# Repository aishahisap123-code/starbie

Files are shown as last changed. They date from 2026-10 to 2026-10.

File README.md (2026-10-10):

# Starcade
Starcade is a motion-controlled handheld arcade pet and retro game console. Inspired by classic handhelds and desktop pets, it brings interactive games, motion sensing, and sound effects together in a custom wing-shaped PCB. Instead of relying solely on traditional buttons, you interact with games, menus, and pet reactions by physically tilting, shaking, and rotating the board.



# What It Is
Starcade is designed to sit on your desk, display custom animations on a bright OLED screen, and react directly to how you handle it. Tilting, rotating the encoder, pressing action buttons, and listening to sound effects and LED animations are all core to the physical experience.

The board includes an ESP32-C3 microcontroller, 0.96" OLED display, 6-axis MPU6050 motion sensor, DHT11 temperature/humidity sensor, addressable WS2812B RGB LEDs, active buzzer, and a rotary encoder inside a compact wing-shaped PCB design. It is USB-C powered and optimized for easy component assembly and custom firmware hacking.

# Why?
This project was created as a complete, hands-on hardware and embedded software tutorial, taking builders all the way from custom PCB layout and Gerber manufacturing to writing full Arduino firmware from scratch.

# Project Status
The custom PCB layout, ground plane generation, Gerber manufacturing exports, and component DRC checks are complete and verified. Starter Arduino IDE code and pin assignment maps are set up to handle display drivers, motion detection, RGB lighting, and menu navigation.

# Software
Firmware/ contains modular, self-contained Arduino IDE sketches for the Seeed Studio XIAO ESP32-C3. Builders customize pin assignments, motion sensitivity, sound effects, LED lighting modes, and sensor readouts at the top of the sketch. See the Firmware/ README for library setup, board manager links, and flashing instructions.

# Repository Contents
PCB/ — KiCad source files, schematic diagrams, and ready-to-upload Gerber fabrication exports (.zip)

Renders/ — 2D/3D front and back PCB renders with custom silkscreen artwork (STARCADE35, AXISAP, and emblems)

Project Guide.md — Step-by-step assembly, soldering, and manufacturing guide

Firmware/ — Arduino IDE starter sketches for OLED graphics, MPU6050 motion tracking, DHT11 environmental readings, WS2812B LEDs, buzzer audio, and rotary menu navigation

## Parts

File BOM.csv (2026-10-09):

# Starcade 35 – bill of materials
<!-- Generated by Half Life from project cmuwsvaz90ai901osuojz3ds5. Edits here are overwritten on the next sync. -->
<!-- Generated: 2026-10-09T14:10:22.091Z -->
> [!NOTE]
> This parts list is mirrored from [Half Life](https://halflife.hackclub.com). Editing it here will not change the platform's copy, and the next sync overwrites this file.
 | Week | Tier | Parts funding
 | --- | --- | ---
 | Week 1 | Tier 1 | $30.00
 | Part | What it's for | Qty | Unit | Total | Vendor
 | --- | --- | --- | --- | --- | ---
 | [ESP32 c3 mini](https://www.aliexpress.com/item/1005008791937363.html?mp=1 | The main brain that runs your software, handles Wi-Fi/Bluetooth, and controls all components. | 1 | $8.34 | $8.34 | [Aliexpress](https://www.aliexpress.com/item/1005008791937363.html?mp=1
 | [MPU-6050 MPU6050 Module](https://www.aliexpress.com/item/1005009668682906.html?mp=1 | accelerometer and gyro used for tilt-based motion controls in games. | 1 | $1.73 | $1.73 | [Aliexpress](https://www.aliexpress.com/item/1005009668682906.html?mp=1
 | [DHT11](https://www.aliexpress.com/item/1005008953430940.html?mp=1 | temp sensor | 1 | $1.40 | $1.40 | [Aliexpress](https://www.aliexpress.com/item/1005008953430940.html?mp=1
 | [pcb board](https://cart.jlcpcb.com/shopcart/cart) | pcb | 1 | $8.67 | $8.67 | [JLCPCB](https://cart.jlcpcb.com/shopcart/cart)
 | [0.96 inch OLED](https://www.aliexpress.com/item/1005006141235306.html?mp=1 | the display | 1 | $0.93 | $0.93 | [Aliexpress](https://www.aliexpress.com/item/1005006141235306.html?mp=1
 | [rotary encoder](https://www.aliexpress.com/item/1005008583446552.html?curPageLogUid=ELZrBR1cT0gn | navigation | 1 | $5.20 | $5.20 | [Aliexpress](https://www.aliexpress.com/item/1005008583446552.html?curPageLogUid=ELZrBR1cT0gn
 | [buzzer](https://www.aliexpress.com/item/1005008789575850.html?mp=1 | make sound | 1 | $1.82 | $1.82 | [Aliexpress](https://www.aliexpress.com/item/1005008789575850.html?mp=1
 | [buttons](https://www.aliexpress.com/item/1005001629177989.html?curPageLogUid=qgexuiVhkgyf | navigation and menu and gameplay | 1 | $1.61 | $1.61 | [Aliexpress](https://www.aliexpress.com/item/1005001629177989.html?curPageLogUid=qgexuiVhkgyf
 | **Parts subtotal** | — | — | — | **$29.70** | —
 | **Tax & shipping** | — | — | — | **$0.00** | —
 | **Total** | — | — | — | **$29.70** | —
$0.30 left of the tier's funding.

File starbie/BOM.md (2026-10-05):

# Starbie — bill of materials

<!-- Generated by Half Life from project cmuvag7340foz01smya712y6w. Edits here are overwritten on the next sync. -->
<!-- Generated: 1970-01-01T00:00:00.000Z -->

> [!NOTE]
> This parts list is mirrored from [Half Life](https://halflife.hackclub.com). Editing it here will not change the platform's copy, and the next sync overwrites this file.

| Week | Tier | Parts funding |
| --- | --- | --- |
| Week 1 | Tier 1 | $30.00 |

_No parts listed yet._

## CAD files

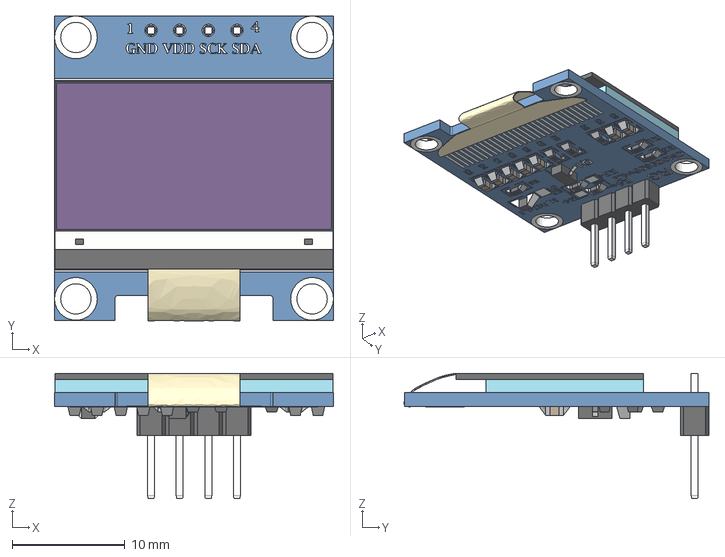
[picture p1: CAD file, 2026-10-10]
starbie/3D Models/0.96'' OLED Display.step
24.8 x 27.1 x 11.1 mm

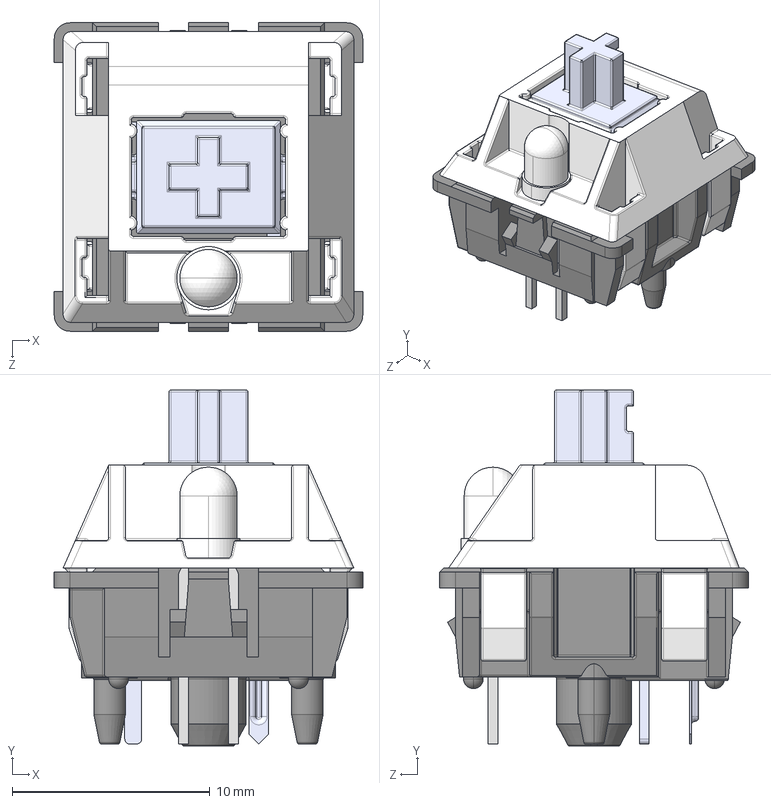
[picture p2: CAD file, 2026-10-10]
starbie/3D Models/Cherry MX.STEP
15.6 x 18.0 x 15.6 mm
Bottom
Pulsador
Top
Pieza5^Cherry MX
Pin1
Pin2
Led 3mm_trans

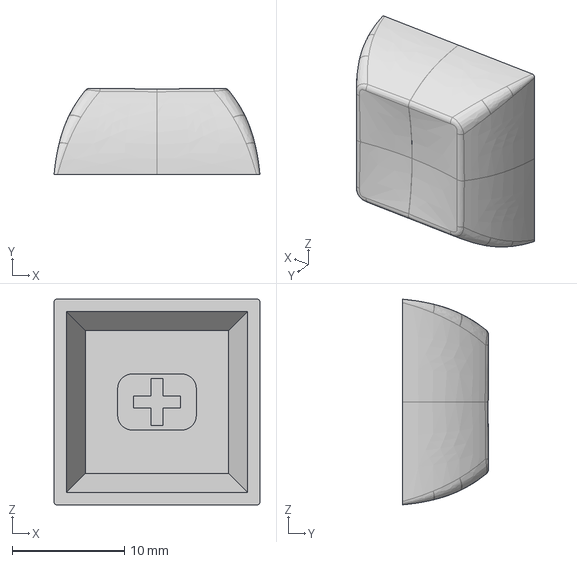
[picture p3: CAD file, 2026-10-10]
starbie/3D Models/DSA_Keycap_CherryMX.step
18.3 x 7.69 x 18.3 mm

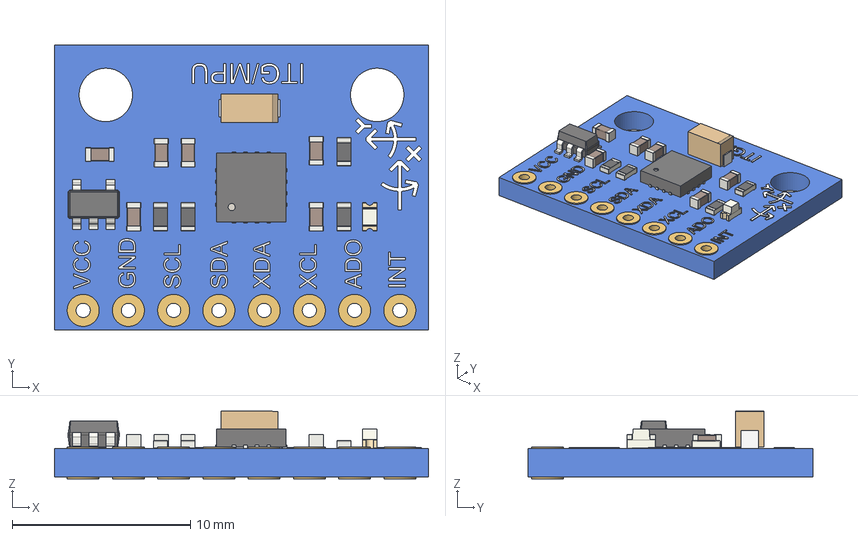
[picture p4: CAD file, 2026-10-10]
starbie/3D Models/GY-521_MPU6050 Accelerometer.step
21.0 x 16.0 x 3.80 mm
PCB
trou1
trou002
trou003
trou004
trou005
trou006
trou007
trou008
Text_X
Symb_Y
Symb_X
Text_Y
Text_VCC
Text_GND
Text_SCL
Text_SDA
Text_XDA
Text_XCL
Text_ADO
Text_INT
R_0603_1608Metric
R_0603_1608Metric001
R_0603_1608Metric002
R_0603_1608Metric003
C_0603_1608Metric
C_0603_1608Metric001
C_0603_1608Metric002
C_0603_1608Metric003
Corps002
Corps001 (Mirror #1)
C_0603_1608Metric004
C_0603_1608Metric005
LED_0603_1608Metric_Castellated
QFN_16_1EP_4x4mm_P065mm_EP21x21mm
Text_ITGMPU
SOT_23_5
Corps001

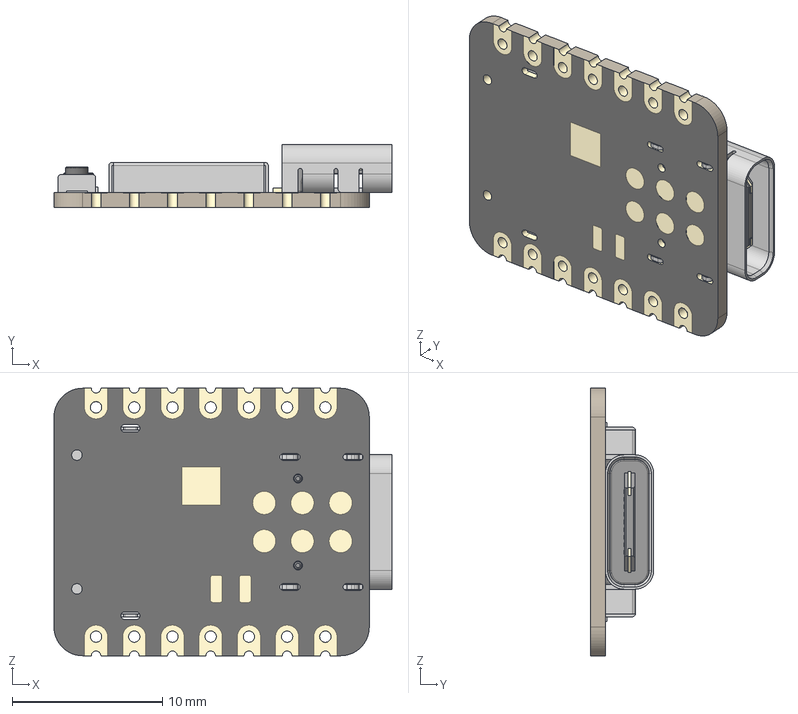
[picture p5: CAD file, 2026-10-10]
starbie/3D Models/Seeed Studio XIAO-ESP32-C3.step
22.5 x 4.21 x 17.8 mm
BOSS-EXTRUDE14_8_
BOSS-EXTRUDE7_4_
BOSS-EXTRUDE7_3_
BOSS-EXTRUDE14_4_
BOSS-EXTRUDE14_2_
BOSS-EXTRUDE14_11_
BOSS-EXTRUDE7_7_
BOSS-EXTRUDE14_9_
BOSS-EXTRUDE14_3_
BOSS-EXTRUDE14_7_
MIRROR2
BOSS-EXTRUDE14_5_
BOSS-EXTRUDE14_12_
BOSS-EXTRUDE7_8_
BOSS-EXTRUDE7_1_
BOSS-EXTRUDE14_10_
BOSS-EXTRUDE7_9_
BOSS-EXTRUDE14_6_
BOSS-EXTRUDE14_1_
BOSS-EXTRUDE7_6_
BOSS-EXTRUDE7_2_
CUT-EXTRUDE5
BOSS-EXTRUDE7_5_
U.FL Connector v1
Button (1) x 2
Shield

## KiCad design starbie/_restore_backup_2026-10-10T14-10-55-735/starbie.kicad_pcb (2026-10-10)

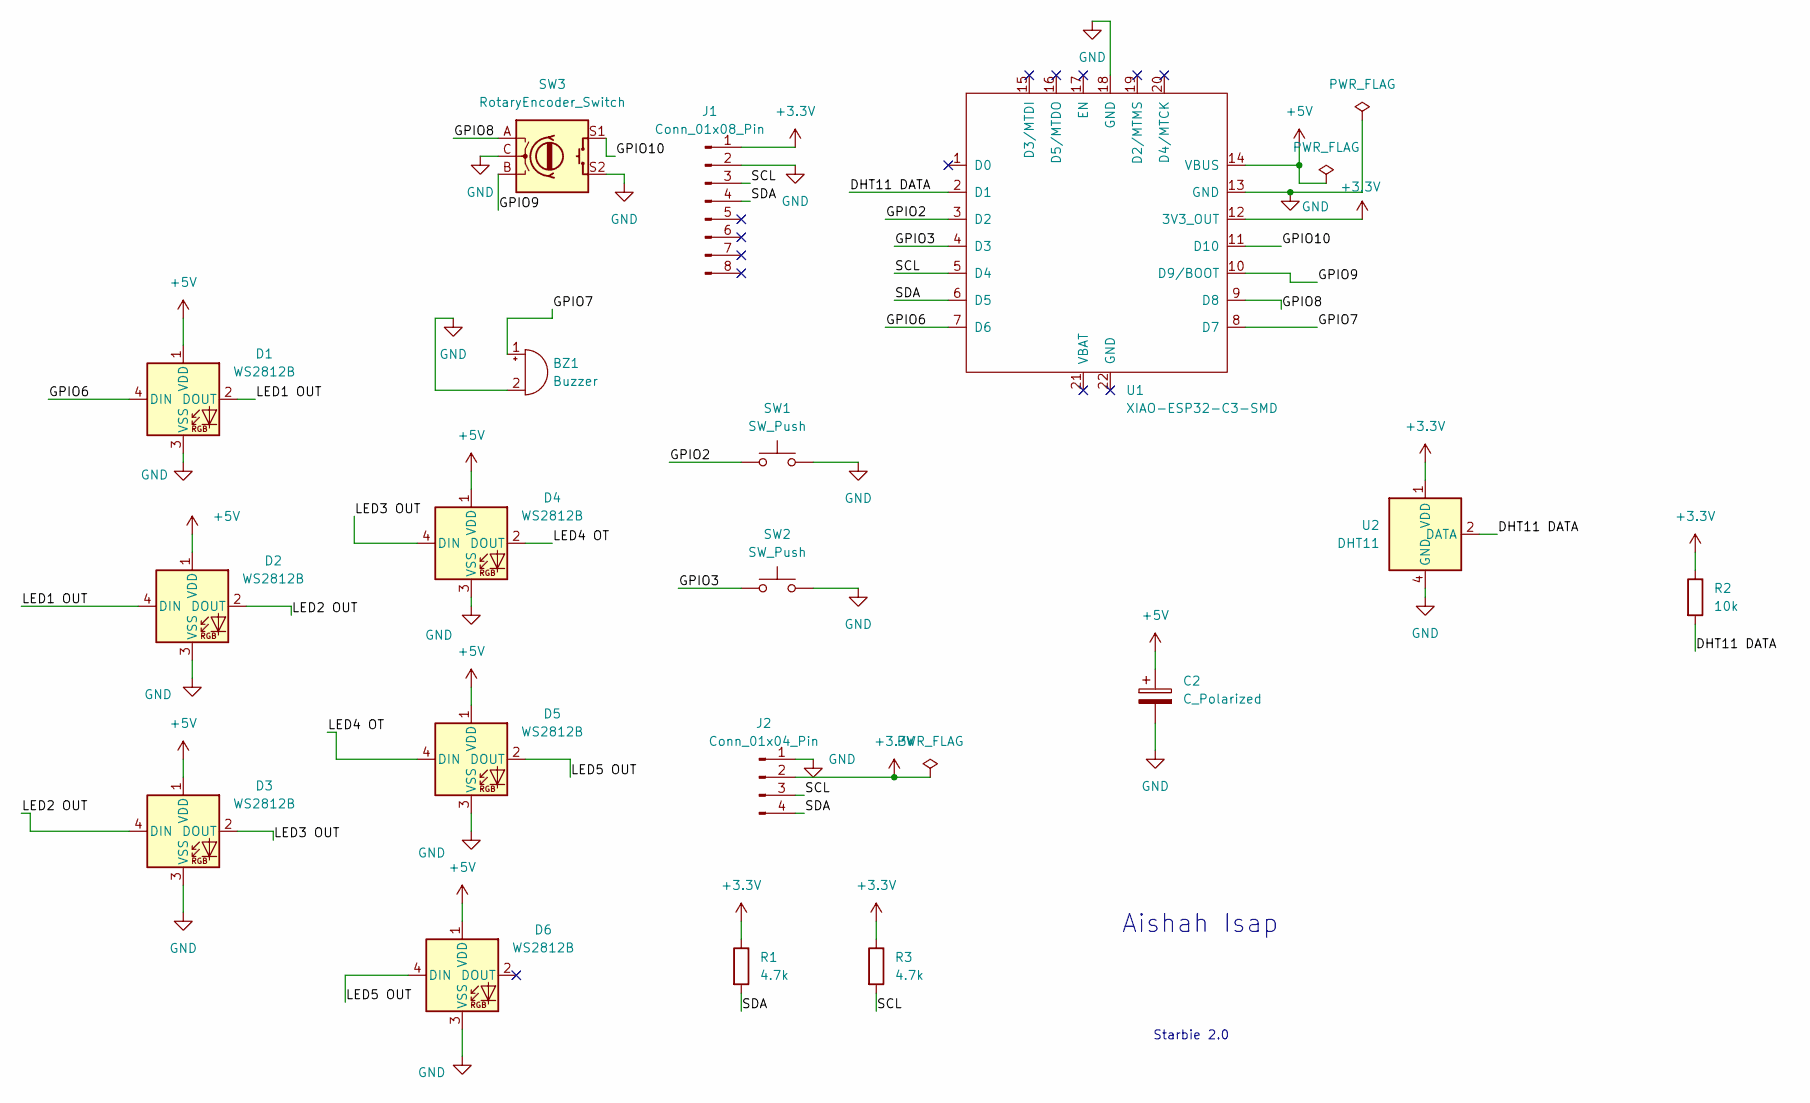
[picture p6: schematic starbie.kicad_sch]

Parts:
BZ1: Buzzer; Buzzer_12x9.5RM7.6
C2: C_Polarized; CP_Radial_D8.0mm_P3.50mm
D1, D2, D3, D4, D5, D6: WS2812B; LED_WS2812B_PLCC4_5.0x5.0mm_P3.2mm
J1: Conn_01x08_Pin; MPU6050_Module
J2: Conn_01x04_Pin; Display_128x64_096_I2C
R1, R3: 4.7k; R_Axial_DIN0204_L3.6mm_D1.6mm_P7.62mm_Horizontal
R2: 10k; R_Axial_DIN0204_L3.6mm_D1.6mm_P7.62mm_Horizontal
SW1, SW2: SW_Push; SW_PUSH_6mm
SW3: RotaryEncoder_Switch; RotaryEncoder_Alps_EC11E-Switch_Vertical_H20mm
U1: XIAO-ESP32-C3-SMD; MCU_Seeed_ESP32C3
U2: DHT11; Aosong_DHT11_5.5x12.0_P2.54mm

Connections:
+3.3V: J1.1, J2.2, R1.1, R2.1, R3.1, U1.12 (3V3_OUT), U2.1 (VDD)
+5V: C2.1, D1.1 (VDD), D2.1 (VDD), D3.1 (VDD), D4.1 (VDD), D5.1 (VDD), D6.1 (VDD), U1.14 (VBUS)
/DHT11 DATA: R2.2, U1.2 (D1), U2.2 (DATA)
/GPIO2: SW1.1, U1.3 (D2)
/GPIO3: SW2.1, U1.4 (D3)
/GPIO6: D1.4 (DIN), U1.7 (D6)
/GPIO7: BZ1.1 (+), U1.8 (D7)
/GPIO8: SW3.A, U1.9 (D8)
/GPIO9: SW3.B, U1.10 (D9/BOOT)
/GPIO10: SW3.S1, U1.11 (D10)
/LED1 OUT: D1.2 (DOUT), D2.4 (DIN)
/LED2 OUT: D2.2 (DOUT), D3.4 (DIN)
/LED3 OUT: D3.2 (DOUT), D4.4 (DIN)
/LED4 OT: D4.2 (DOUT), D5.4 (DIN)
/LED5 OUT: D5.2 (DOUT), D6.4 (DIN)
/SCL: J1.3, J2.3, R3.2, U1.5 (D4)
/SDA: J1.4, J2.4, R1.2, U1.6 (D5)
GND: BZ1.2 (-), C2.2, D1.3 (VSS), D2.3 (VSS), D3.3 (VSS), D4.3 (VSS), D5.3 (VSS), D6.3 (VSS), J1.2, J2.1, SW1.2, SW2.2, SW3.C, SW3.S2, U1.13 (GND), U1.18 (GND), U2.4 (GND)

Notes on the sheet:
Starbie 2.0
Aishah Isap

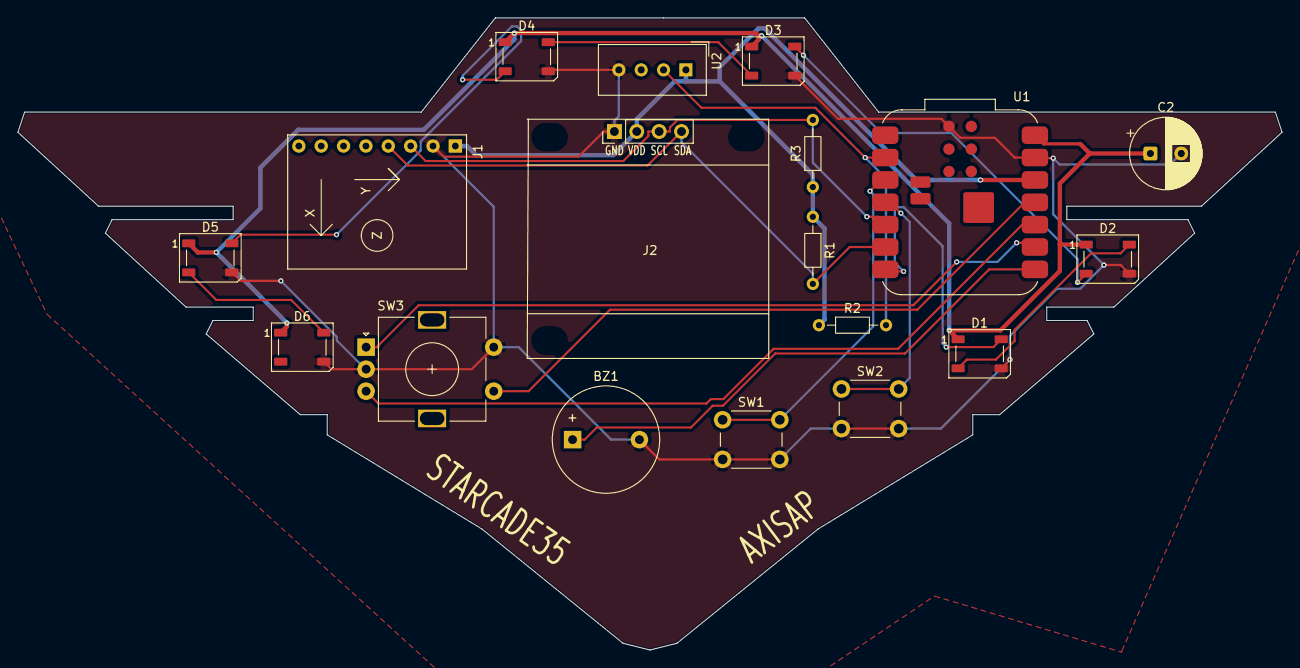
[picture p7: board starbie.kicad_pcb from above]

Board: 2 copper layers, 143.6 x 71.8 mm, 18 parts (0 on the bottom side), 18 nets.

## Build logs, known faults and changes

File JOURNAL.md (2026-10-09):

# Starcade 35 – devlog

<!-- Generated by Half Life from project cmuwsvaz90ai901osuojz3ds5. Edits here are overwritten on the next sync. -->
<!-- Generated: 2026-10-07T19:00:14.272Z -->

> [!NOTE]
> This devlog is mirrored from [Half Life](https://halflife.hackclub.com). Editing it here will not change the platform's copy, and the next sync overwrites this file.

> A tiny motion-controlled digital pet, basically a desktop Tamagotchi. Totally not a Starboy. I have revised the starter project and added extra features such as 6x RGB LEDs, a buzzer, a rotary encoder, dual push buttons, and a motion sensor, turning it into a live environmental desk companion that instantly doubles as a retro handheld for games like Snake.

| Week | Tier | Hours logged | Entries |
| --- | --- | --- | --- |
| Week 1 | Tier 1 | 10h | 2 |

## Contents

1. [2026-10-06 – Session 1: Setting Up KiCad, Schematic Design & My First Battle with Footprint Errors](#2026-10-06-session-1-setting-up-kicad-schematic-design-my-fi)
2. [2026-10-07 – Starcade Hardware Session 2: Final PCB Layout, Routing, and Error Cleared](#2026-10-07-starcade-hardware-session-2-final-pcb-layout-rout)

## Design

### 2026-10-06 – Session 1: Setting Up KiCad, Schematic Design & My First Battle with Footprint Errors

**4.5h**

Session 1: Setting Up KiCad, Schematic Design & My First Battle with Footprint Errors

Today was all about kicking off Starbie 2.0, the upgraded version of the HackClub original project, now powered by the Seeed Studio XIAO ESP32-C3. The plan was to get everything built in KiCad's schematic editor, clear out electrical errors, map all the physical footprints, and finally push everything into the PCB editor so I can start laying out the board.

It turned into a solid 4.5-hour grind (13:30 to 18:00), but I went from having zero files to a fully connected, error-free PCB layout ready for routing! Here is a breakdown of everything that happened, what went wrong, and how I fixed it.

Downloading KiCad & Importing Custom Libraries
Before drawing a single wire, I had to get the software environment ready. Because Starbie 2.0 uses specific hardware modules, like an I2C 0.96" OLED display and an MPU6050 accelerometer, the standard KiCad built-in library didn't have everything I needed out of the box.

	I downloaded KiCad and grabbed custom component libraries (.pretty folders for footprints and .sym files for schematic symbols).

	I went into KiCad's Library Manager to manually link these imported symbol and footprint paths so they’d actually show up when searching for components.

Drawing the Schematic & Fighting ERC Errors
Once the canvas was ready, I dropped in the main brain (XIAO ESP32-C3) alongside the rest of Starbie 2.0's hardware lineup:
	Sensors & Input: DHT11 temperature/humidity sensor, MPU6050 6-DOF gyro, 2x tactile push buttons, and a 5-pin rotary encoder.
	Outputs & Audio: 6x WS2812B addressable RGB LEDs, a buzzer, and the header connector for the OLED screen.

	Passives: Decoupling capacitors and pull-up/limiting resistors.
Wiring everything up was smooth until I ran the Electrical Rules Check (ERC), which immediately threw red flags all over my power rails (+3.3V, +5V, and GND).

The ERC Confusion:
KiCad is super picky, it expects every power rail to have a dedicated power output pin driving it. Because the XIAO board feeds power through regular module pins rather than a traditional regulator symbol, KiCad assumed my power lines were floating in mid-air without any power source.

The Fix (PWR_FLAG):
I learned about a special KiCad symbol called the PWR_FLAG (Power Flag). It isn't a physical part that gets soldered to the board, it's just a dummy signal for KiCad’s internal checker. Dropping three PWR_FLAG symbols onto the canvas and wiring them to +3.3V, +5V, and GND cleared the ERC errors instantly.

Footprint Assignment Chaos
With the schematic validated, I opened the Footprint Assignment Tool to link every schematic symbol to an actual physical hardware footprint. This step turned out to be a massive game of trial-and-error:
	Hunting Down the Rotary Encoder:
I spent way too long trying to find the right footprint for the 5-pin rotary encoder. Typing generic terms like "encoder" into the search bar wasn't pulling up what I needed. I had to manually clear the search filters, navigate into the Rotary_Encoder library category, and find RotaryEncoder_Alps_EC11E-Switch_Vertical_H20mm—which matches the exact 12mm vertical knob package I'm using.

	Accidental Microchip Packages:
KiCad assigned some bizarre default footprints to my passive parts. My 12mm buzzer and 470 µF electrolytic capacitor somehow got mapped to SOIC-8 (a tiny 8-pin surface-mount microchip package!). My push buttons were also accidentally mapped to full Cherry MX mechanical keyboard switch footprints.

	Cleaning Up the Mappings:
I manually went line-by-line to correct everything:
	Resistors (R1, R2): Set to axial through-hole (R_Axial_DIN0204).
	LEDs (D1–D6): Set to standard 5050 surface-mount addressable LEDs (LED_WS2812B_PLCC4_5.0x5.0mm).
	Capacitor (C2) & Buzzer (BZ1): Fixed from SOIC-8 to a radial through-hole footprint (CP_Radial_D8.0mm) and a standard 12mm buzzer footprint (Buzzer_12x9.5mm).
Converting to PCB & The 8 Red Pad Errors

With all footprints assigned, I hit Tools → Update PCB from Schematic (or F8), expecting my board layout to pop open cleanly. Instead, KiCad blocked the export with 8 red errors:
Why this happened:
The original Starbie project used a simple 14-pin DIP footprint for the main board. But because Starbie 2.0 takes advantage of additional pin connections on the Seeed XIAO ESP32-C3 symbol (pins 15 through 22 for extra sensing/audio), the schematic symbol had 22 active pins. When KiCad tried to map a 22-pin symbol onto a 14-pin footprint, it freaked out because pads 15–22 physically didn't exist on that DIP layout!

The Fix:
I jumped back into the Footprint Assignment Tool and changed U1's footprint from the old imported DIP model to rf_module:mcu_seed_esp32c3. This footprint includes all 22 surface-mount castellated and bottom pads matching the XIAO board layout.

Smooth Sailing into the PCB Editor
I ran F8 again, and this time the error count dropped to 0!
There were two minor warnings regarding SW3 pad MP (mechanical mounting pads on the rotary encoder casing that don't have electrical connections in the schematic), but those are strictly mechanical and safe to ignore.
I clicked Update PCB, closed the dialog, and boom, all my component footprints popped onto the black PCB canvas connected by green lines. Starbie 2.0 is officially ready for placement and trace routing!

Key Lessons Learned Today
	PWR_FLAG is a lifesaver: If your board gets power through a header or module rather than an on-board regulator symbol, ERC will complain until you manually add power flags.
	Check pin counts on module footprints: Always make sure your footprint has the exact same number of physical pads as your schematic symbol pins, especially when upgrading a design to use more feature pins on a microcontroller.

	Don't trust default footprint mappings: Double-check passive footprints before exporting so you don't accidentally try soldering a capacitor onto an IC chip footprint!

Total Time Spent: 4.5 hours (13:30 – 18:00)





















### 2026-10-07 – Starcade Hardware Session 2: Final PCB Layout, Routing, and Error Cleared

**5.5h**

Starcade Hardware Session 2: Final PCB Layout, Routing, and Error Cleared

Today Objective
My main goal today was to finish up the entire pcb design, place down every single component, shape the board itself, and fix all remaining visual and design errors so the hardware side is completely done.

What I Did Today
I spent time laying out all the physical components on the board and shaping the actual pcb outline. I designed the board shape specifically so it works well for both motion sensing and gaming controls, keeping the layout comfortable and functional. When placing the seeed studio xiao esp32 module, I made sure it was positioned hanging slightly off the edge of the board, which keeps the antenna area clear for a better signal and allows easy access to the usb port.

After finalizing the board edge boundaries, I started routing all the electrical connections across the entire PCB. I used different trace widths depending on what the line was doing, using thick traces for power lines to handle the current smoothly and thinner traces for all the signal lines connecting the microcontroller to the sensors, screen, leds, and buttons.

I also worked on the 3d models for the xiao esp32 and the oled screen, adjusting their height offsets and rotations to fix visual glitching where parts were clipping through the board surface. I verified the rest of the components, including the addressable rgb leds, the buzzer, the motion sensor chip, the rotary encoder footprint holes, and the custom dallas wings logo on the silkscreen layer. To cap off the session, I ran design checks on the whole board and cleared up every single error so the entire layout is clean.

Mistakes I Ran Into and How I Fixed Them
Downloaded Files Turning Into Web Code
One annoying problem I ran into was downloading 3d files for the rotary encoder dial. When saving files from CAD sites, the browser was saving raw website code instead of proper 3d model data, even though the file name ended with a model extension like step or wrl.

Because the files were secretly web code, the software could not read them and left the encoder invisible in the 3d preview. After realizing the downloaded file was corrupted text, I remembered that 3d models are purely cosmetic anyway. The footprint drill holes and copper pads on the PCB are what actually matter for manufacturing, so I removed the bad file link to keep the project files clean.

Misaligned Pins and Model Offsets
Another issue was that generic 3d models did not align with the footprint holes right away. When loading in models, the pins would often be rotated sideways by ninety degrees or floating off to the side of the actual pads.

This happened because the center point of the 3d model file did not match the center point of my pcb footprint. To fix it, I went into the properties, turned the model along the z axis, and shifted the offset values until the pins lined up over the through holes, which confirmed that physical footprint pad locations always take priority over visual models.

Routing Violations and Board Boundary Clearance
While routing the thick power lines and thin signal wires across the board, I ran into a few design check errors where traces were running too close to the board edge boundaries or crossing each other improperly.

I had to go back through the tight spots, nudge the traces further inside the board edge constraints, and adjust the spacing between signal lines. Fixing those clearances brought the error count down to zero and made sure the board will be manufactured without short circuits or fabrication flaws.

Wrap Up
With all the components placed, the custom shape defined, the routing completed with correct wire thicknesses, and every single error cleared out, the physical pcb design is officially finished. The board is fully laid out and ready for the next phase.

Total time spent: 5.5 hours (12:30 - 14:30, 15:30 - 18:00)





















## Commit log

2026-10-06 Update JOURNAL.md with KiCad setup details
    Documented the process of setting up KiCad for the Starbie 2.0 project, including troubleshooting ERC errors, footprint assignments, and lessons learned during the PCB layout preparation.
2026-10-06 Update JOURNAL.md with KiCad setup details
    Documented the process of setting up KiCad for the Starbie 2.0 project, including schematic design, footprint assignments, and resolving ERC errors.
2026-10-06 Insert new image in JOURNAL.md
    Added a new image to the journal.
2026-10-18 Add BOM link to README
2026-10-19 Add bill of materials for Starcade 35 project
    Added detailed bill of materials for the Starcade 35 project, including parts, costs, and vendor information.
2026-10-19 Revise BOM with updated parts and funding details
    Updated the bill of materials with detailed parts list and links.
2026-10-26 Add starbie-B Silkscreen file
2026-10-30 Expand README with project features and functionalities
    Added detailed features of the Virtual Pet Simulator, Environment & Sensor Monitoring, Built-In Mini-Games, and Hardware & Audio-Visual Extras.
